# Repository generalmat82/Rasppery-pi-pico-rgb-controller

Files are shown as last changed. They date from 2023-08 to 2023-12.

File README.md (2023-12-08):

This Project was a project I started when I was in need of a RGB controller for rgb strips I had on my desk. I thus decided to make it a lot more expensive by doing it myself!
I wanted to be able to controll the RGB strips from my computer, I also wanted it to be mostly made by me.

I separated the project into 3 parts:
* Frontend
  * This would be the section with a webpage to controll the controller. 
* Backend
  * This would be the place where all the current values was being saved; With a bit of moddifications we could get rid of this section entirely.
* Controller
  * Finally this is the place that actually controlls the rgb strips.

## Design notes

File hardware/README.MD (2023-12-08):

This section of the repositary is for the hardware nececity of the project.

# Project nececity:
When I started the project I wanted to be able to controll the 2 RGB strips on my desk through WIFI since the remotes were pretty broken and why not?
The project needed the following:
* Be able to run both RGB strips separately.
* Be able to controll them with my computer.
* Be fully made by me(except the components and things I couldnt do myself)

# Hardware components:
For the project I used:
* 3 [IRLB8721PBF-ND](https://www.digikey.ca/en/products/detail/infineon-technologies/IRLB8721PBF/2127670) per strips
* 1 [RASPBERRY PI PICO W RP2040](https://www.digikey.ca/en/products/detail/raspberry-pi/SC0918/16608263)
* 1 [S7002-ND](https://www.digikey.ca/en/products/detail/sullins-connector-solutions/PPTC041LFBN-RC/810144) per strips
* I also had a laptop running Ubuntu for the front end and backend that was communicating with the RPI Pico W.

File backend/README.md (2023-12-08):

The backend is made with a flask server.
The backend is used to save all current values of the controller. It would also treat modifications of the rgb strips.
The rgb strips can be modified through either the frontend website or by sending http requests containing json to the backend.

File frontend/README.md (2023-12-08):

The front end is ran by a npm package named [http-server](https://www.npmjs.com/package/http-server).
This runs the webpage to easily communicate with the backend.
# How to start it:
In my case I ran both frontend and backend on a old laptop runing ubuntu. 
To run the front end follow the following steps:

1. First you need to have nodeJs installed.
2. Then you can install http-server by running `npm i http-server` in the terminal.
3.

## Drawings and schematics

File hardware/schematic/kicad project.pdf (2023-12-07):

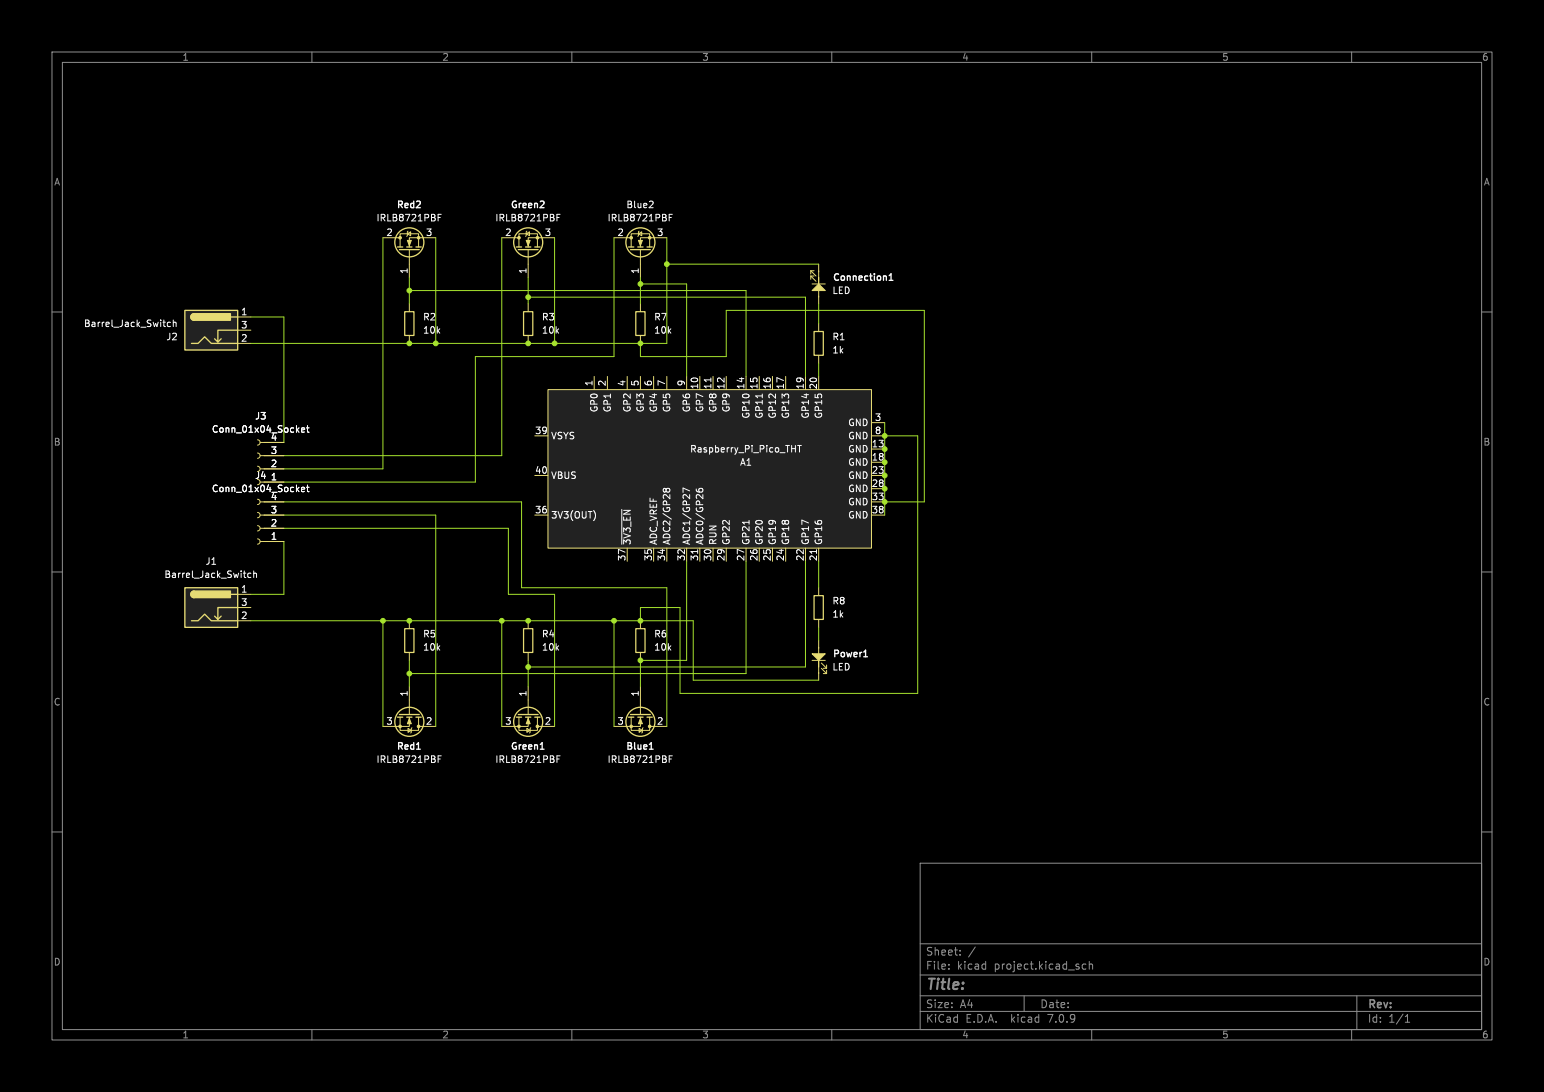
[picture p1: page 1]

2 GP15 20 GP16 21 GP17 22 GND 23 GP18 24 GP19 25 GP20 26 GP21 27 GND 28 GP22 29 GND 3 RUN 30 ADC0/GP26 31 ADC1/GP27 32 GND 33 ADC2/GP28 34 ADC_VREF 35

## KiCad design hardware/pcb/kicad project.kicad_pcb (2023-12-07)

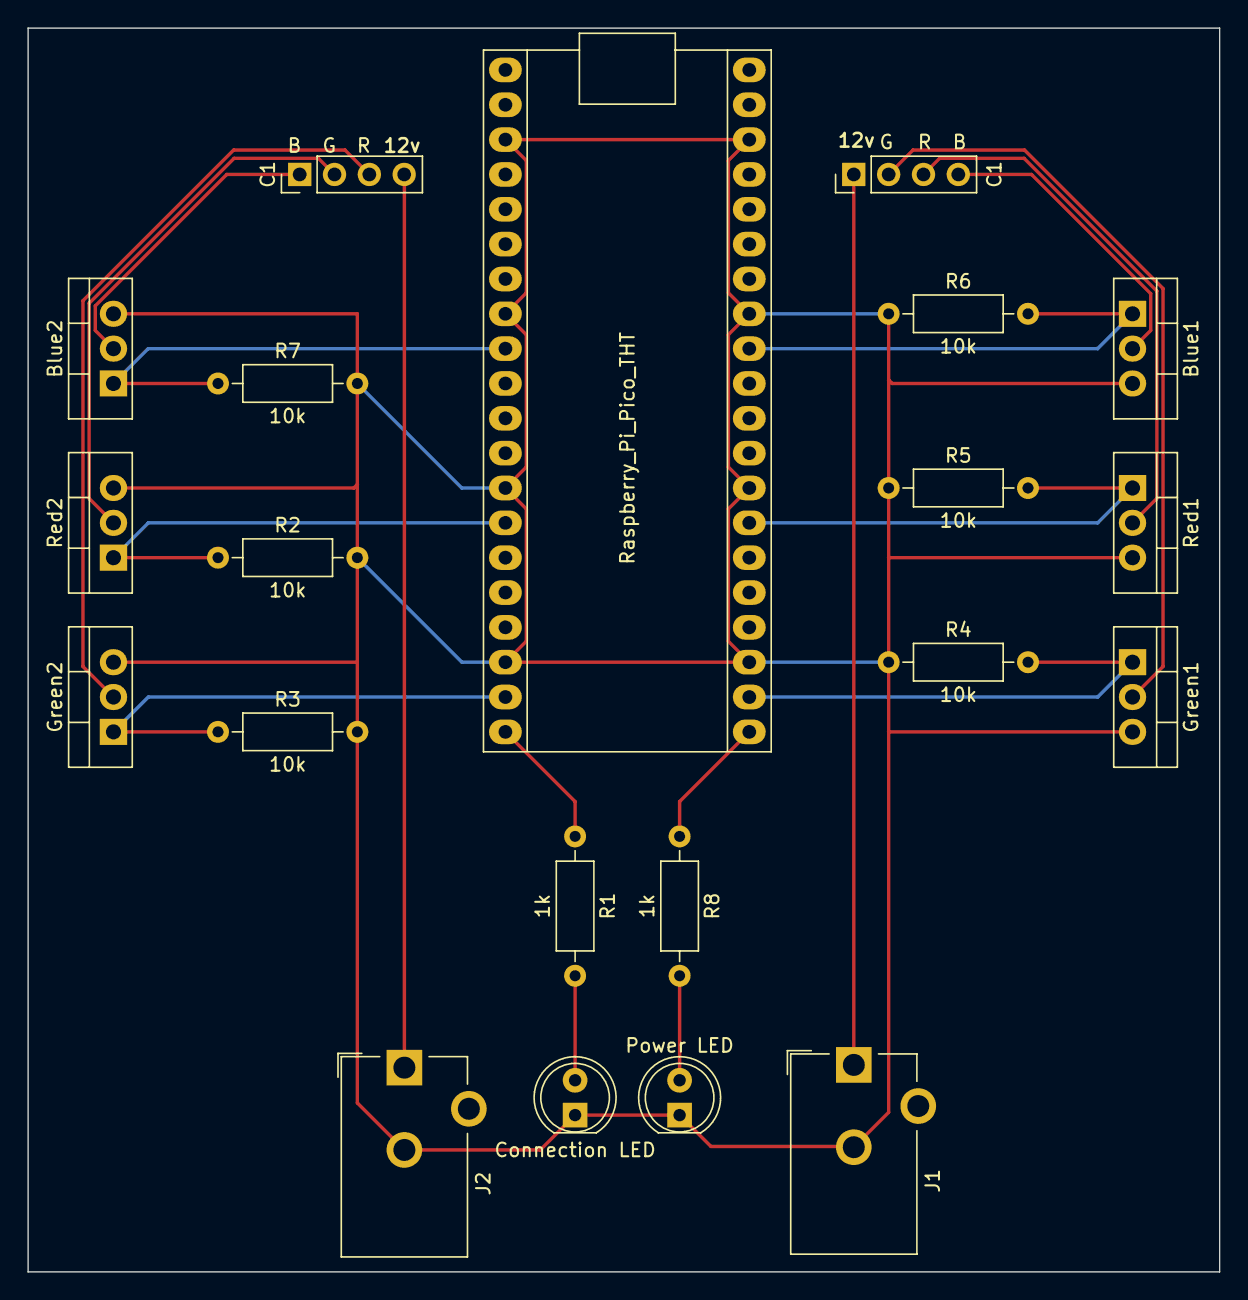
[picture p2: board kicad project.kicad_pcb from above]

Board: 2 copper layers, 86.9 x 90.7 mm, 21 parts (0 on the bottom side), 19 nets.

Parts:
A1: Raspberry_Pi_Pico_THT; raspberry_pi_pico_THT
Blue1, Blue2: IRLB8721PBF; TO-220-3_Vertical
C1, C1#2: Conn_01x04_Socket; PinHeader_1x04_P2.54mm_Vertical
Connection LED: LED; LED_D5.0mm
Green1, Green2: IRLB8721PBF; TO-220-3_Vertical
J1, J2: Barrel_Jack_Switch; BarrelJack_CUI_PJ-102AH_Horizontal
Power LED: LED; LED_D5.0mm
R1, R8: 1k; R_Axial_DIN0207_L6.3mm_D2.5mm_P10.16mm_Horizontal
R2, R3, R4, R5, R6, R7: 10k; R_Axial_DIN0207_L6.3mm_D2.5mm_P10.16mm_Horizontal
Red1, Red2: IRLB8721PBF; TO-220-3_Vertical

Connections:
unnamed: A1.32 (ADC1/GP27), Blue1.1 (G), R6.2
unnamed: A1.9 (GP6), Blue2.1 (G), R7.1
unnamed: A1.14 (GP10), R2.1, Red2.1 (G)
unnamed: A1.19 (GP14), Green2.1 (G), R3.1
unnamed: A1.20 (GP15), R1.1
unnamed: A1.21 (GP16), R8.1
unnamed: A1.22 (GP17), Green1.1 (G), R4.2
unnamed: A1.27 (GP21), R5.2, Red1.1 (G)
unnamed: Blue1.2 (D), C1.4
unnamed: A1.3 (GND), A1.8 (GND), A1.13 (GND), A1.18 (GND), A1.23 (GND), A1.28 (GND), A1.33 (GND), A1.38 (GND), Blue1.3 (S), Blue2.3 (S), Connection LED.1, Green1.3 (S), Green2.3 (S), J1.2, J2.2, Power LED.1, R2.2, R3.2, R4.1, R5.1, R6.1, R7.2, Red1.3 (S), Red2.3 (S)
unnamed: Blue2.2 (D), C1#2.1
unnamed: Connection LED.2, R1.2
unnamed: C1.2, Green1.2 (D)
unnamed: C1#2.3, Green2.2 (D)
unnamed: C1#2.2, Red2.2 (D)
unnamed: C1#2.4, J2.1
unnamed: C1.1, J1.1
unnamed: C1.3, Red1.2 (D)
unnamed: Power LED.2, R8.2

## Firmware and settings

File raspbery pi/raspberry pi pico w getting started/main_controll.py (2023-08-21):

"""
todo -0- add power led indicator, color states for rgb for each strips on webpage
/todo/ -1- Make circuit fit on 1 breadboard
/todo/ -2- Make sure circuit 1 breadboard is working
/todo/ -3- Make circuit fit on solder breadboard
/todo/ -4- Make sure circuit 2 breadboard is working
/todo/ -5- solder
/todo/ -6- test soldered circuit
todo -7- hope it works
"""

import json
import network
import socket
from time import sleep
from picozero import pico_temp_sensor, pico_led
import machine
from secret import *


connectionLed = machine.Pin(14, machine.Pin.OUT)
powerled = machine.Pin(15, machine.Pin.OUT)
powerled.on()

strip1R = machine.PWM(machine.Pin(18))
strip1R.freq(1000)      # Set the frequency value
strip1RVal = 0     #initial value of the red of strip 1

strip1G = machine.PWM(machine.Pin(16))
strip1G.freq(1000)      # Set the frequency value
strip1GVal = 0     #initial value of the green of strip 1

strip1B = machine.PWM(machine.Pin(21))
strip1B.freq(1000)      # Set the frequency value
strip1BVal = 0     #initial value of the blue of strip 1



strip2R = machine.PWM(machine.Pin(19))
strip2R.freq(1000)      # Set the frequency value
strip2RVal = 0     #initial value of the red of strip 2

strip2G = machine.PWM(machine.Pin(17))
strip2G.freq(1000)      # Set the frequency value
strip2GVal = 0     #initial value of the green of strip 2

strip2B = machine.PWM(machine.Pin(20))
strip2B.freq(1000)      # Set the frequency value
strip2BVal = 0     #initial value of the blue of strip 2




def connect():
    #Connect to WLAN
    wlan = network.WLAN(network.STA_IF)
    wlan.active(True)
    wlan.connect(ssid, password)
    while wlan.isconnected() == False:
        print('Waiting for connection...')
        connectionLed.toggle()
        sleep(1)
    ip = wlan.ifconfig()[0]
    print(f'Connected on {ip}')
    return ip


def open_socket(ip):
    # Open a socket
    address = (ip, 80)
    connection = socket.socket()
    connection.bind(address)
    connection.listen(1)
    print(connection)
    return connection




def webpage():
    """generates the html file for the webpage

    Returns:
        str: string with the html information
    """
    
    if powerled.value() == 1:
        pwrLedState = 'ON'
    else:
        pwrLedState = 'OFF'
    
    if connectionLed.value() == 1:
        connLedState = 'ON'
    else:
        connLedState = 'OFF'
    temperature = pico_temp_sensor.temp
    with open('index.html', 'r') as f:
        html = f.read()
    html = html.replace('{temperature}', str(temperature))
    html = html.replace('{pwrLedState}', pwrLedState)
    html = html.replace('{ConnectLedState}', connLedState)
    html = html.replace('{strip1RVal}',str(strip1RVal))
    html = html.replace('{strip1GVal}',str(strip1GVal))
    html = html.replace('{strip1BVal}',str(strip1BVal))
    html = html.replace('{strip2RVal}',str(strip2RVal))
    html = html.replace('{strip2GVal}',str(strip2GVal))
    html = html.replace('{strip2BVal}',str(strip2BVal))
    return str(html)



class request_handler:
    def __init__(self, request):
        self.request = request
        print("raw request: ")
        print(self.request)

        self.extract_data()

    def extract_data(self):
        requestSplit = self.request.split()
        if (requestSplit[0] == "b'GET"):
            self.requestData = requestSplit[1]
            self.methode = "GET"
        else: #elif (requestSplit[0] == "b'POST"):
            self.requestData = requestSplit[-1]
            self.methode = "POST"
        print("requestData: ")
        print(self.requestData)
        self.requestDataList = self.requestData.split("/")
        print(self.requestDataList)
        self.requestDataList.pop(0)
        if self.methode == "POST":
            self.requestDataList.pop(0)
            self.requestDataList[-1] = self.requestDataList[-1][:len(self.requestDataList[-1]) - len("'")]
        print("requestDataList: ")
        print(self.requestDataList)

    def extract_params(self):
        self.stripStates = {"strip1": {"update":False, "valR": 0, "valG": 0, "valB": 0}, "strip2": {"update":False,"valR": 0, "valG": 0, "valB":0}}
        try:
            if self.requestDataList[1] == "1":
                self.stripStates["strip1"]["update"] = True
                self.stripStates["strip1"]["valR"] = int(self.requestDataList[3])
                self.stripStates["strip1"]["valG"] = int(self.requestDataList[5])
                self.stripStates["strip1"]["valB"] = int(self.requestDataList[7])
            elif self.requestDataList[1] == "2":
                self.stripStates["strip2"]["update"] = True
                self.stripStates["strip2"]["valR"] = int(self.requestDataList[3])
                self.stripStates["strip2"]["valG"] = int(self.requestDataList[5])
                self.stripStates["strip2"]["valB"] = int(self.requestDataList[7])
            else:
                self.stripStates = False
        except IndexError:
            self.stripStates = False
 




def serve(connection):
    global strip1RVal, strip1GVal, strip1BVal, strip2RVal, strip2GVal, strip2BVal
    #Start a web server
    state = "off"
    pico_led.off()
    pico_led.on()
    sleep(1)
    pico_led.off()
    sleep(1)
    pico_led.on()
    sleep(1)
    pico_led.off()
    temperature = 0
    while True:
        client, addr = connection.accept()
        print(f'Connection from {addr} accepted')

        request = client.recv(1024)
        request = str(request)
        

        answer = request_processing(request)
        client.send(answer)
        client.close()


def update_rgb(request):
    """updates the rgb values of the specified strip

    Args:
        request (request_handler): the handled request object
    Returns:
        Nan: returns nothing
    """
    global strip1RVal, strip1GVal, strip1BVal, strip2RVal
    if request.stripStates["strip1"]["update"]:
        print("update strip1")
        strip1R.duty_u16(int(request.stripStates["strip1"]["valR"]*500))
        strip1RVal = request.stripStates["strip1"]["valR"]
        strip1G.duty_u16(int(request.stripStates["strip1"]["valG"]*500))
        strip1GVal = request.stripStates["strip1"]["valG"]
        strip1B.duty_u16(int(request.stripStates["strip1"]["valB"]*500))
        strip1BVal = request.stripStates["strip1"]["valB"]
    if request.stripStates["strip2"]["update"]:
        print("update strip2")
        strip2R.duty_u16(int(request.stripStates["strip2"]["valR"]*500))
        strip2RVal = request.stripStates["strip2"]["valR"]
        strip2G.duty_u16(int(request.stripStates["strip2"]["valG"]*500))
        strip2GVal = request.stripStates["strip2"]["valG"]
        strip2B.duty_u16(int(request.stripStates["strip2"]["valB"]*500))
        strip2BVal = request.stripStates["strip2"]["valB"]
# end def


def request_processing(request):
    """process the request to determine what would be necesary to do

    Args:
        request (str): the request to be processed

    Returns:
        request_handler, bool: a request_handler object or a boolean indicating the action necessary
    """
    request = request_handler(request)
    #-------------------------------------------------------------------------------------------------------------------------------
    #*section that determines what action to take

    request.extract_params()

    if request.methode == "GET":
        answer = get_request_processing(request)
    elif request.methode == "POST":
        answer = post_request_processing(request)
    return answer




def get_request_processing(request):
    """determines what action to take if the request is a GET request

    Args:
        request (request_handler): handled request object
    """
    if request.requestData == "/stop/":
        machine.reset()
        return
    elif request.requestData == "/togglePwrLed/": 
        powerled.toggle()
        return webpage()
    
    elif request.requestData == "/toggleConnectLed/":
        connectionLed.toggle()
        return webpage()

    if request.stripStates != False:
        print(request.stripStates)
        update_rgb(request)
    if request.requestData == "/getRgbValue":
        vals= {
            "strip1": {
                "valR": strip1RVal,
                "valG": strip1GVal,
                "valB": strip1BVal
            },
            "strip2": {
                "valR": strip2RVal,
                "valG": strip2GVal,
                "valB": strip2BVal
            }
        }
        return json.dumps(vals)
    elif request.requestData == "/getPwrLedState/":
        if powerled.value() == 1:
            state = {"PwrLedState": "ON"}
            return json.dumps(state)
        else:
            state = {"PwrLedState": "OFF"}
            return json.dumps(state)
    elif request.requestData == "/getConnectLedState/":
        if connectionLed.value() == 1:
            state = {"ConnectLedState": "ON"}
            return json.dumps(state)
        else:
            state = {"ConnectLedState": "OFF"}
            return json.dumps(state)
    elif request.requestData == "/getTemperature/":
        temp = {"temp": pico_temp_sensor.temp}
        return json.dumps(temp)
    elif request.requestData == "/":
        return webpage()
    elif request.requestData == "/requestList/":
        possibleRequest = {
            "GET": {
                "stop": {
                    "description": "stops the machine",
                    "requestCommand": "/stop/"
                },
                "togglePwrLed": {
                    "description": "toggles the power led",
                    "requestCommand": "/togglePwrLed/",
                    "answer": "Html page"
                },
                "toggleConnectLed": {
                    "description": "toggles the connection led",
                    "requestCommand": "/toggleConnectLed/",
                    "answer": "Html page"
                },
                "getRgbValue": {
                    "description": "gets the rgb values of the specified strip",
                    "requestCommand": "/getRgbValue",
                    "answer": "dict containing rgb values"
                },
                "getPwrLedState": {
                    "description": "gets the power led state",
                    "requestCommand": "/getPwrLedState",
                    "answer": "state of the power led"
                },
                "getConnectLedState": {
                    "description": "gets the connection led state",
                    "requestCommand": "/getConnectLedState",
                    "answer": "state of the connection led"
                },
                "getTemperature": {
                    "description": "gets the temperature",
                    "requestCommand": "/getTemperature",
                    "answer": "temperature"
                },
            },
            "POST": {
                "changeRBGValue": {
                    "description": "changes the rgb values of the specified strip",
                    "requestCommand": "/strip/PARAM1/valR/PARAM2/valG/PARAM3/valB/PARAM4",
                    "params": {
                        "PARAM1": "int specifying the strip to change",
                        "PARAM2": "int specifying the red value",
                        "PARAM3": "int specifying the green value",
                        "PARAM4": "int specifying the blue value",
                    },
                    "answer": "None"
                },
                "togglePwrLed": {
                    "description": "toggles the power led",
                    "requestCommand": "/togglePwrLed/",
                    "answer": "new state of the power led"
                },
                "toggleConnectLed": {
                    "description": "toggles the connection led",
                    "requestCommand": "/toggleConnectLed/",
                    "answer": "new state of the connection led"
                }
            }
        }
        return json.dumps(possibleRequest)
    else:
        answer = {"answer": "Invalid request"}
        return json.dumps(answer)


def post_request_processing(request):
    """determines what action to take if the request is a POST request

    Args:
        request (request_handler): handled request object
    """
    if request.stripStates!= False:
        print(request.stripStates)
        update_rgb(request)
    if request.requestData == "/togglePwrLed/":
        powerled.toggle()
        if powerled.value() == 1:
            state = "ON"
        else:
            state = "OFF"
        answer = {"pwrLedState": state}
        return json.dumps(answer)
    elif request.requestData == "/toggleConnectLed/":
        connectionLed.toggle()
        if connectionLed.value() == 1:
            state = "ON"
        else:
            state = "OFF"
        answer = {"connectLedState": state}
        return json.dumps(answer)
    else:
        answer = {"answer": "Invalid request"}
        return json.dumps(answer)





try:
    ip = connect()
    connection = open_socket(ip)
    serve(connection)
except:
    machine.reset()

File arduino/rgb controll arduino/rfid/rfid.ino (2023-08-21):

/*
 * --------------------------------------------------------------------------------------------------------------------
 * Example sketch/program showing how to read data from a PICC to serial.
 * --------------------------------------------------------------------------------------------------------------------
 * This is a MFRC522 library example; for further details and other examples see: https://github.com/miguelbalboa/rfid
 * 
 * Example sketch/program showing how to read data from a PICC (that is: a RFID Tag or Card) using a MFRC522 based RFID
 * Reader on the Arduino SPI interface.
 * 
 * When the Arduino and the MFRC522 module are connected (see the pin layout below), load this sketch into Arduino IDE
 * then verify/compile and upload it. To see the output: use Tools, Serial Monitor of the IDE (hit Ctrl+Shft+M). When
 * you present a PICC (that is: a RFID Tag or Card) at reading distance of the MFRC522 Reader/PCD, the serial output
 * will show the ID/UID, type and any data blocks it can read. Note: you may see "Timeout in communication" messages
 * when removing the PICC from reading distance too early.
 * 
 * If your reader supports it, this sketch/program will read all the PICCs presented (that is: multiple tag reading).
 * So if you stack two or more PICCs on top of each other and present them to the reader, it will first output all
 * details of the first and then the next PICC. Note that this may take some time as all data blocks are dumped, so
 * keep the PICCs at reading distance until complete.
 * 
 * @license Released into the public domain.
 * 
 * Typical pin layout used:
 * -----------------------------------------------------------------------------------------
 *             MFRC522      Arduino       Arduino   Arduino    Arduino          Arduino
 *             Reader/PCD   Uno/101       Mega      Nano v3    Leonardo/Micro   Pro Micro
 * Signal      Pin          Pin           Pin       Pin        Pin              Pin
 * -----------------------------------------------------------------------------------------
 * RST/Reset   RST          9             5         D9         RESET/ICSP-5     RST
 * SPI SS      SDA(SS)      10            53        D10        10               10
 * SPI MOSI    MOSI         11 / ICSP-4   51        D11        ICSP-4           16
 * SPI MISO    MISO         12 / ICSP-1   50        D12        ICSP-1           14
 * SPI SCK     SCK          13 / ICSP-3   52        D13        ICSP-3           15
 *
 * More pin layouts for other boards can be found here: https://github.com/miguelbalboa/rfid#pin-layout
 */

#include <SPI.h>
#include <MFRC522.h>

#define RST_PIN         5          // Configurable, see typical pin layout above
#define SS_PIN          53         // Configurable, see typical pin layout above

MFRC522 mfrc522(SS_PIN, RST_PIN);  // Create MFRC522 instance

void setup() {
	Serial.begin(9600);		// Initialize serial communications with the PC
	while (!Serial);		// Do nothing if no serial port is opened (added for Arduinos based on ATMEGA32U4)
	SPI.begin();			// Init SPI bus
	mfrc522.PCD_Init();		// Init MFRC522
	delay(4);				// Optional delay. Some board do need more time after init to be ready, see Readme
	mfrc522.PCD_DumpVersionToSerial();	// Show details of PCD - MFRC522 Card Reader details
	Serial.println(F("Scan PICC to see UID, SAK, type, and data blocks..."));
}

void loop() {
	// Reset the loop if no new card present on the sensor/reader. This saves the entire process when idle.
	if ( ! mfrc522.PICC_IsNewCardPresent()) {
		return;
	}

	// Select one of the cards
	if ( ! mfrc522.PICC_ReadCardSerial()) {
		return;
	}

	// Dump debug info about the card; PICC_HaltA() is automatically called
	mfrc522.PICC_DumpToSerial(&(mfrc522.uid));
}

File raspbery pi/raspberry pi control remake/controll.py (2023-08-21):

import machine
from picozero import pico_temp_sensor, pico_led

#===============================================================================================================================

class rgb_strip:
    def __init__(self, pinR, pinG, pinB):
        #- RGB values
        self.vals = {"R": 0, "G": 0, "B": 0}
        #- RGB pin setup
        
        def pwm_pin_setup(pin:int, freq:int) -> machine.PWM:
            """makes a PWM pin

            Args:
                pin (int): what pin to use
                freq (int): frequency in wanted

            Returns:
                machine.PWM: a pwm object
            """
            pwm = machine.PWM(machine.Pin(pin)) # type: ignore
            pwm.freq(freq)
            return pwm

        stripR = pwm_pin_setup(pinR, 1000)
        stripG = pwm_pin_setup(pinG, 1000)
        stripB = pwm_pin_setup(pinB, 1000)
        self.pins = {"R": stripR, "G": stripG, "B": stripB}


    def update_rgb(self,R,G,B):
        print("updateing strip")
        print(R,G,B)
        print("updating R")
        self.update_pin(R, "R")
        print("updating G")
        self.update_pin(G, "G")
        print("updating B")
        self.update_pin(B, "B")

    def update_pin(self, val, name):
        print("updating pin")
        print("updating val")
        self.vals[name] = val
        print("updated val:"+str(self.vals[name]))
        print("updating pwm")
        self.pins[name].duty_u16(self.vals[name]*500)
        print("updated pwm")


#===============================================================================================================================


class led:
    def __init__(self, pin):
        self.pin = machine.Pin(pin, machine.Pin.OUT)
        self.state = False

    def on(self):
        self.pin.on()
        self.state = True

    def off(self):
        self.pin.off()
        self.state = False

    def toggle(self):
        self.pin.toggle() # type: ignore
        self.state = not self.state


#¦¦¦¦¦¦¦¦¦¦¦¦¦¦¦¦¦¦¦¦¦¦¦¦¦¦¦¦¦¦¦¦¦¦¦¦¦¦¦¦¦¦¦¦¦¦¦¦¦¦¦¦¦¦¦¦¦¦¦¦¦¦¦¦¦¦¦¦¦¦¦¦¦¦¦¦¦¦¦¦¦¦¦¦¦¦¦¦¦¦¦¦¦¦¦¦¦¦¦¦¦¦¦¦¦¦¦¦¦¦¦¦¦¦¦¦¦¦¦¦¦¦¦¦¦¦¦

strip1 = rgb_strip(19, 17, 20)
strip2 = rgb_strip(18, 16, 21)

pwrLed = led(15)
connectLed = led(14)

#¦¦¦¦¦¦¦¦¦¦¦¦¦¦¦¦¦¦¦¦¦¦¦¦¦¦¦¦¦¦¦¦¦¦¦¦¦¦¦¦¦¦¦¦¦¦¦¦¦¦¦¦¦¦¦¦¦¦¦¦¦¦¦¦¦¦¦¦¦¦¦¦¦¦¦¦¦¦¦¦¦¦¦¦¦¦¦¦¦¦¦¦¦¦¦¦¦¦¦¦¦¦¦¦¦¦¦¦¦¦¦¦¦¦¦¦¦¦¦¦¦¦¦¦¦¦¦

def update_rgb(stripStates):
    """updates the rgb values of the specified strip
    Args:
        request (request_handler): the handled request object
    Returns:
        Nan: returns nothing
    """
    try:
        if stripStates["strip_id"] == 1:
            print("updating strip 1")
            strip1.update_rgb(stripStates["value"]["R"], stripStates["value"]["G"], stripStates["value"]["B"])
            return {"strip_id" : 1, "vals" : {"R" : strip1.vals["R"], "G" : strip1.vals["G"], "B" : strip1.vals["B"]}}, 200
        elif stripStates["strip_id"] == 2:
            strip2.update_rgb(stripStates["value"]["R"], stripStates["value"]["G"], stripStates["value"]["B"])
            return {"strip_id" : 2, "vals" : {"R" : strip2.vals["R"], "G" : strip2.vals["G"], "B" : strip2.vals["B"]}}, 200
        else:
            return {"error": "invalid strip id"}, 400
    except:
        return {"error": "error occurred"}, 500
#===============================================================================================================================

def toggle_led(led):
    print("toggling led")
    if led == "pwr":
        print("toggleing pwr led")
        pwrLed.toggle()
        print("toggled pwr led")
    elif led == "connect":
        print("toggleing connect led")
        connectLed.toggle()

#===============================================================================================================================

def set_led(led, val):
    if led == "pwr":
        pwrLed.on() if val else pwrLed.off()
    elif led == "connect":
        connectLed.on() if val else connectLed.off()

#===============================================================================================================================

def get_led_state(led):
    if led == "pwr":
        return pwrLed.state
    elif led == "connect":
        return connectLed.state

#===============================================================================================================================

def get_all():
    val1R = strip1.vals["R"]
    val1G = strip1.vals["G"]
    val1B = strip1.vals["B"]

    val2R = strip2.vals["R"]
    val2G = strip2.vals["G"]
    val2B = strip2.vals["B"]

    val12RGB = {
        "strip1" : {
            "valR" : val1R,
            "valG" : val1G,
            "valB" : val1B
        },
        "strip2" : {
            "valR" : val2R,
            "valG" : val2G,
            "valB" : val2B
        }
    }


    temp = pico_temp_sensor.temp
    connectLedState = connectLed.pin.value() 
    pwrLedState = pwrLed.pin.value()


    data = {
        "rgbVal" : val12RGB,
        "temp" : temp,
        "connectLed" : connectLedState,
        "pwrLed" : pwrLedState
    }
    return data




#¦¦¦¦¦¦¦¦¦¦¦¦¦¦¦¦¦¦¦¦¦¦¦¦¦¦¦¦¦¦¦¦¦¦¦¦¦¦¦¦¦¦¦¦¦¦¦¦¦¦¦¦¦¦¦¦¦¦¦¦¦¦¦¦¦¦¦¦¦¦¦¦¦¦¦¦¦¦¦¦¦¦¦¦¦¦¦¦¦¦¦¦¦¦¦¦¦¦¦¦¦¦¦¦¦¦¦¦¦¦¦¦¦¦¦¦¦¦¦¦¦¦¦¦¦¦¦

class temp_sensor:
    def __init__(self,pin) -> None:
        self.adc = machine.ADC(pin)
    def get_tempC(self):
        ADC_voltage = self.adc.read_u16() * (3.3 / (65535))
        temperature_celcius = 27 - (ADC_voltage - 0.706)/0.001721
        print("Temperature: {}°C ".format(temperature_celcius))
        return temperature_celcius
    def get_tempF(self):
        ADC_voltage = self.adc.read_u16() * (3.3 / (65535))
        temperature_celcius = 27 - (ADC_voltage - 0.706)/0.001721
        temp_fahrenheit=32+(1.8*temperature_celcius)
        print("Temperature: {}°F".format(temp_fahrenheit))
        return temp_fahrenheit

internal_temp_sensor = temp_sensor(4)
internal_temp_sensor.get_tempF()

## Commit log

2023-08-22 made good looking buttons
2023-08-28 tryed to fix it up had issues
    [main.py, sync_time.py]
2023-12-07 for adding info about hardware
    [kicad project.kicad_pcb]
